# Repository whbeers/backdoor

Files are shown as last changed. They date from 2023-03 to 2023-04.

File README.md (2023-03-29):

# Backdoor Distortion Effect

This is my take on the ProCo "Rat" distortion effect, designed in [KiCAD](https://www.kicad.org/).  The design is based on widely available schematics and pretty true to the original Rat, with only a couple part value swaps that came from experimentation on a breadboard with my daughter. (She was involved in every stage of the development of this effect, and learned a ton!)

The board is built on the ["Noise Floor"](https://github.com/whbeers/noise_floor) pedal platform, which provides basic power protection, audio IO, and a footswitch with LED indicator.

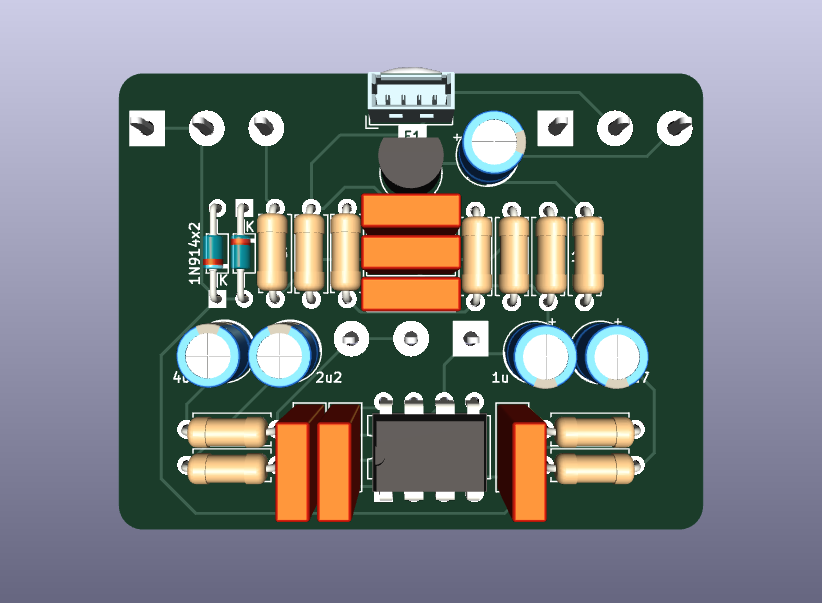
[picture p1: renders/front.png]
Front render

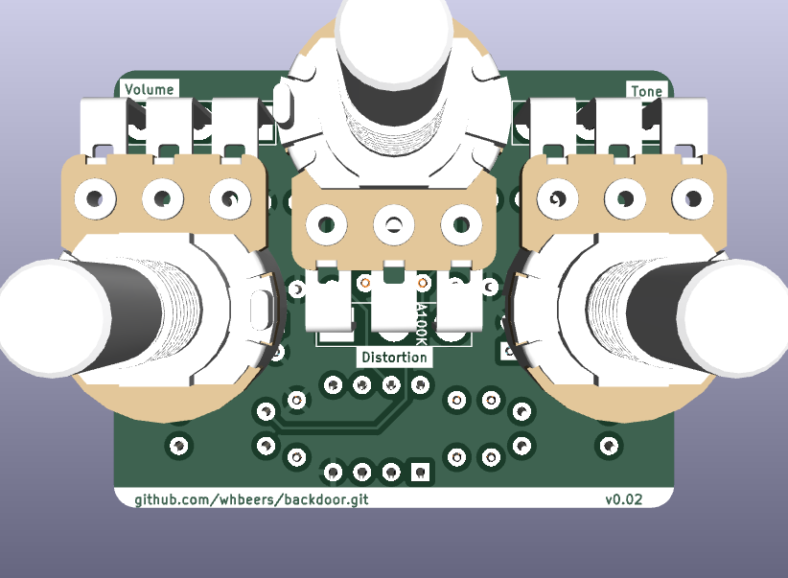
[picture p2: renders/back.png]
Back render

Schematic SVG
[Schematic PDF](schematics/backdoor-latest.pdf)

## Credit
The initial breadboarding utilized the schematic included in the ProCo Rat Analysis at [Electrosmash](https://www.electrosmash.com/proco-rat).

The Rat has a really interesting history - to learn more about it I recommend the [JHS Show episode on the subject](https://www.youtube.com/watch?v=QfwpClT_26E), and for more circuit analysis Brian Wampler has published [several](https://www.youtube.com/watch?v=zBGKdnlh4Ws) [youtube](https://www.youtube.com/watch?v=IAt-hgqrocI) [videos](https://www.youtube.com/watch?v=U2ZOTbfAcNs) going over the circuit and potential tweaks, including their own (tweaked) clone.

Thanks as always to the folks on the [freestompboxes.org](https://www.freestompboxes.org/) forum for feedback and suggestions.

Potentiometer 3D model courtesy [Vasily Kashirin](https://grabcad.com/vasily.kashirin-1).

*I am not affiliated with any of the brands, sites, or products named in this overview.*

## Versioning

My pcb designs utilize the following versioning scheme (I'll add to this as I produce more revisions):
 - v0.0XX: A candidate design that has not yet been produced and tested.
 - v0.XX: A design that has been produced, tested, and any initial errors addressed.

## Name
*The name "Backdoor" is a reflection of the nature of the effect (a RAT) and security nerdery.*

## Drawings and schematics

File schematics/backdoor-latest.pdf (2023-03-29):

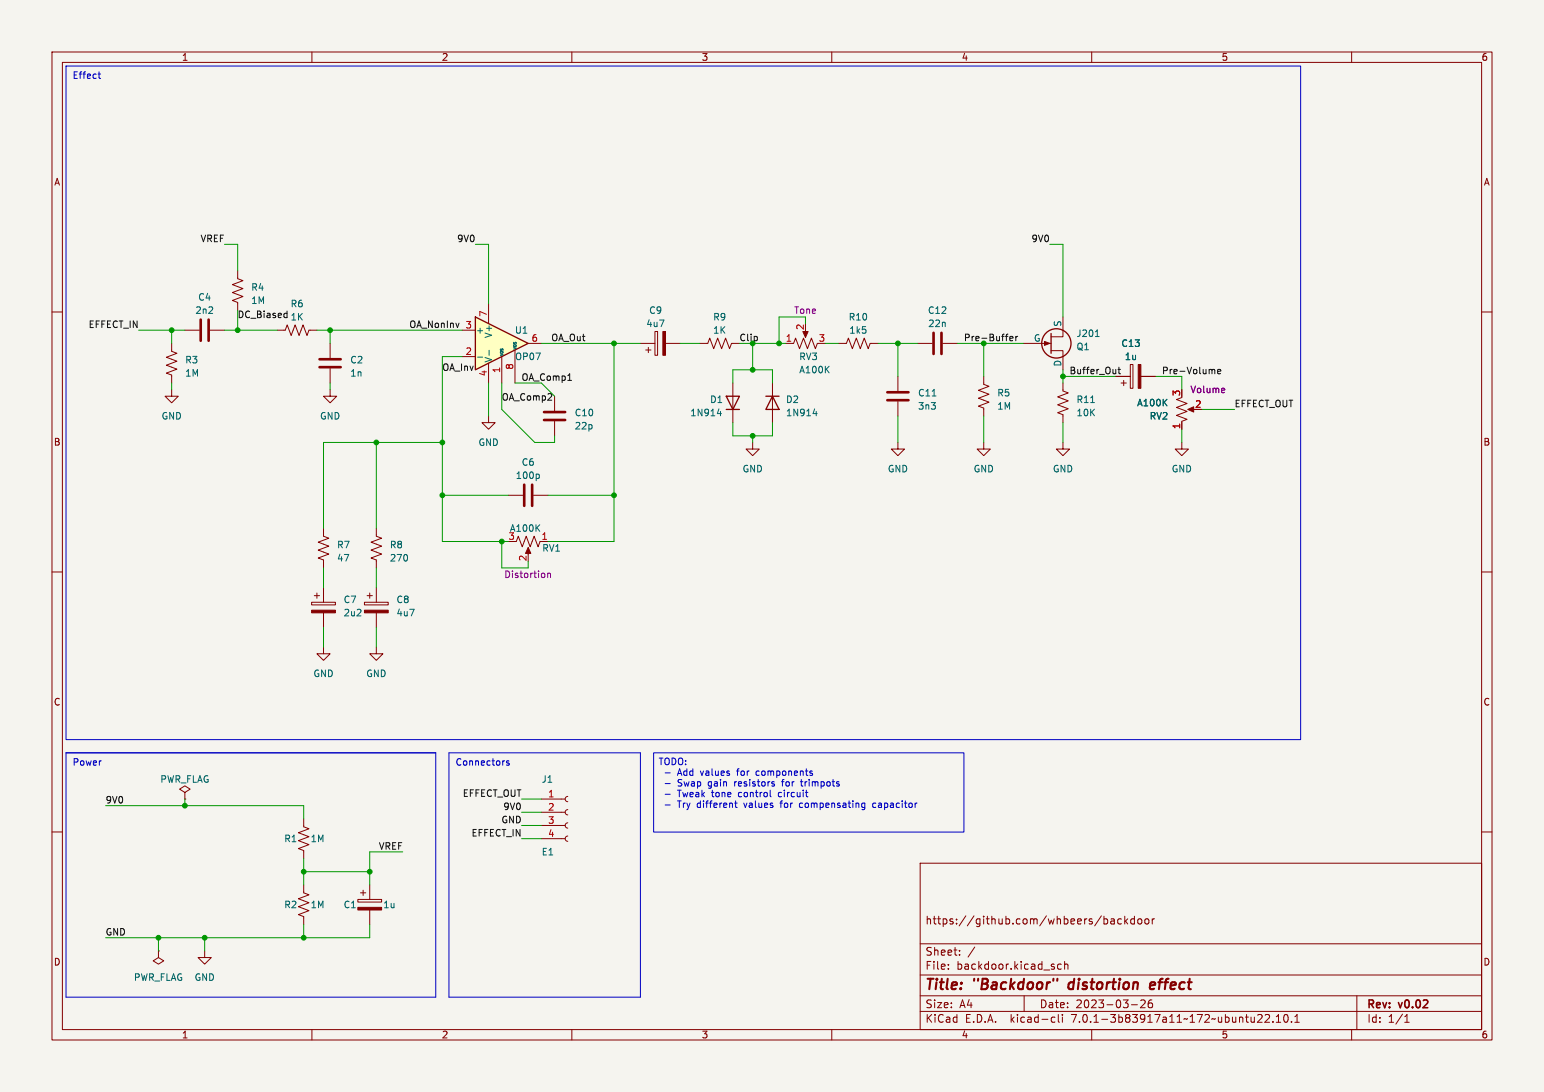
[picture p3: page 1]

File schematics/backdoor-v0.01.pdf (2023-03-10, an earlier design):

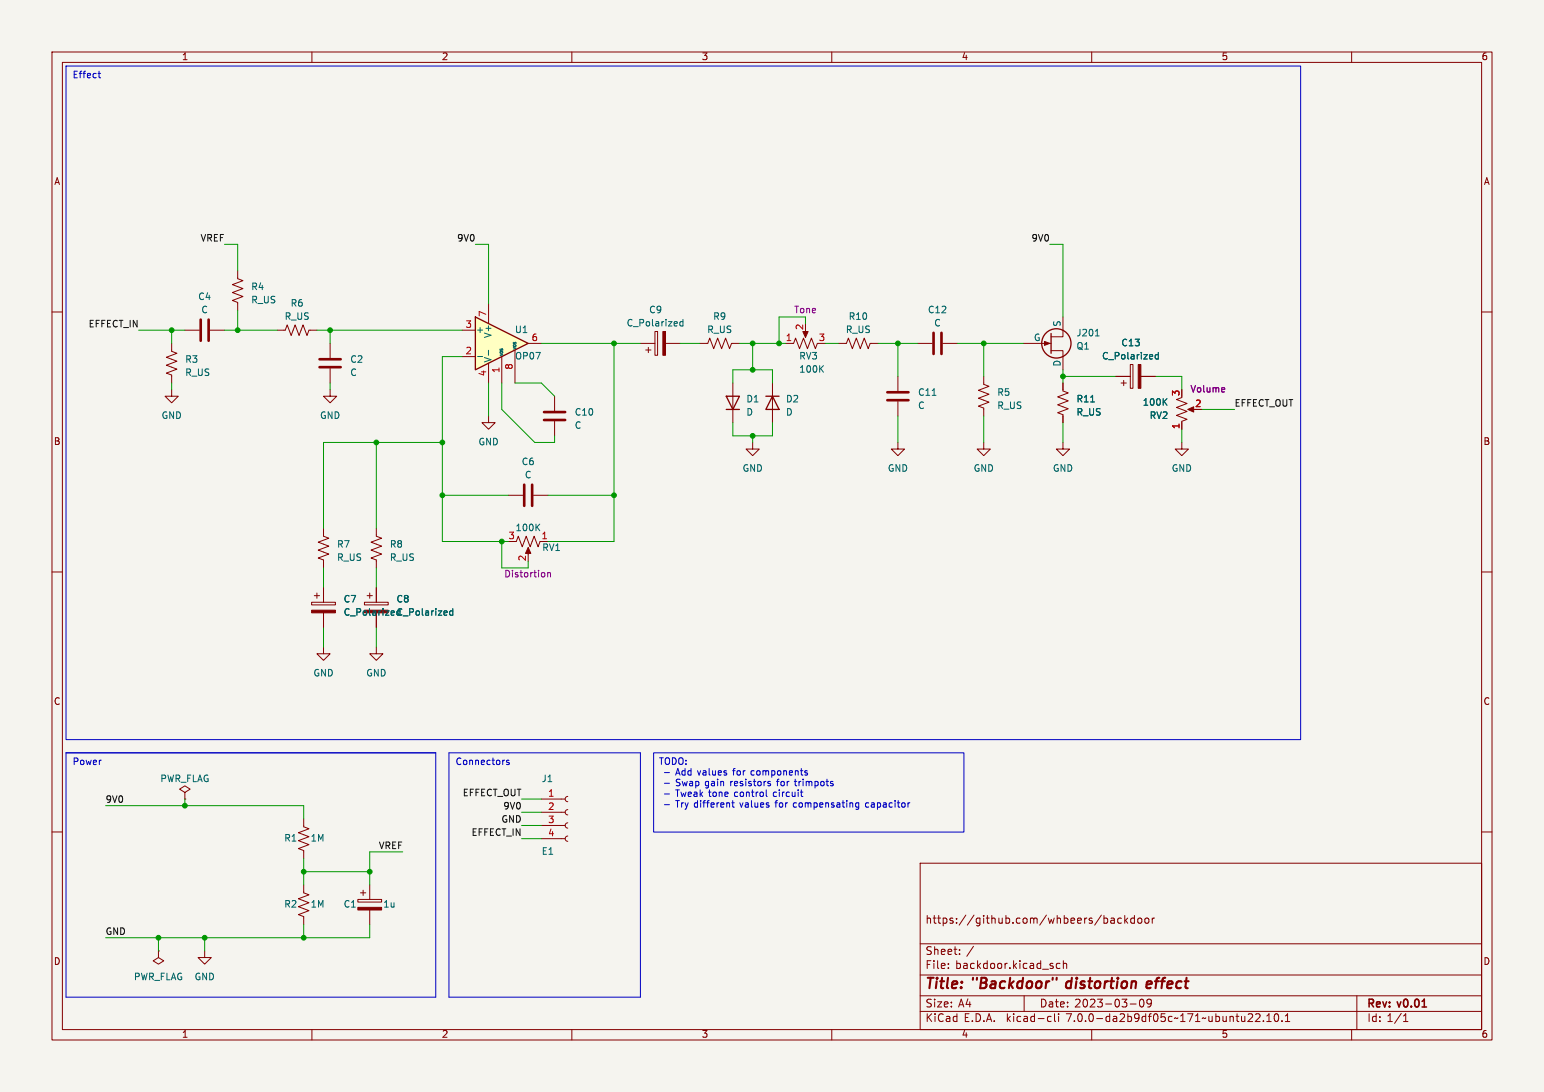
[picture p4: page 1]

- Swap gain resistors for trimpots

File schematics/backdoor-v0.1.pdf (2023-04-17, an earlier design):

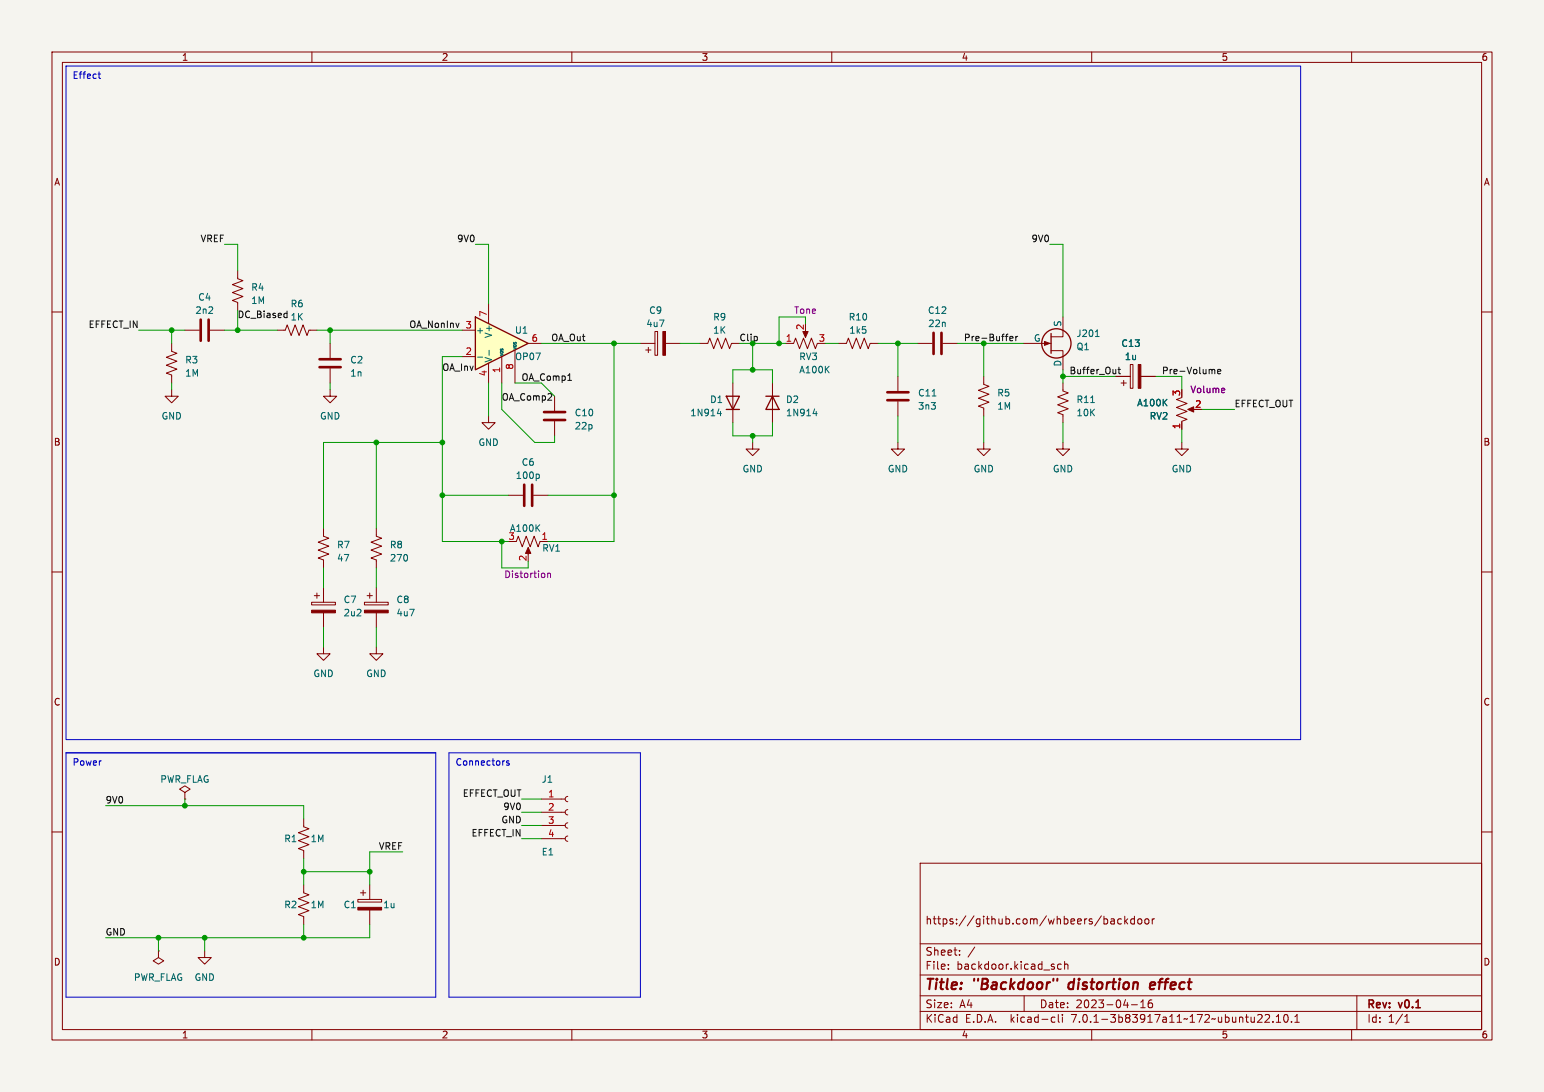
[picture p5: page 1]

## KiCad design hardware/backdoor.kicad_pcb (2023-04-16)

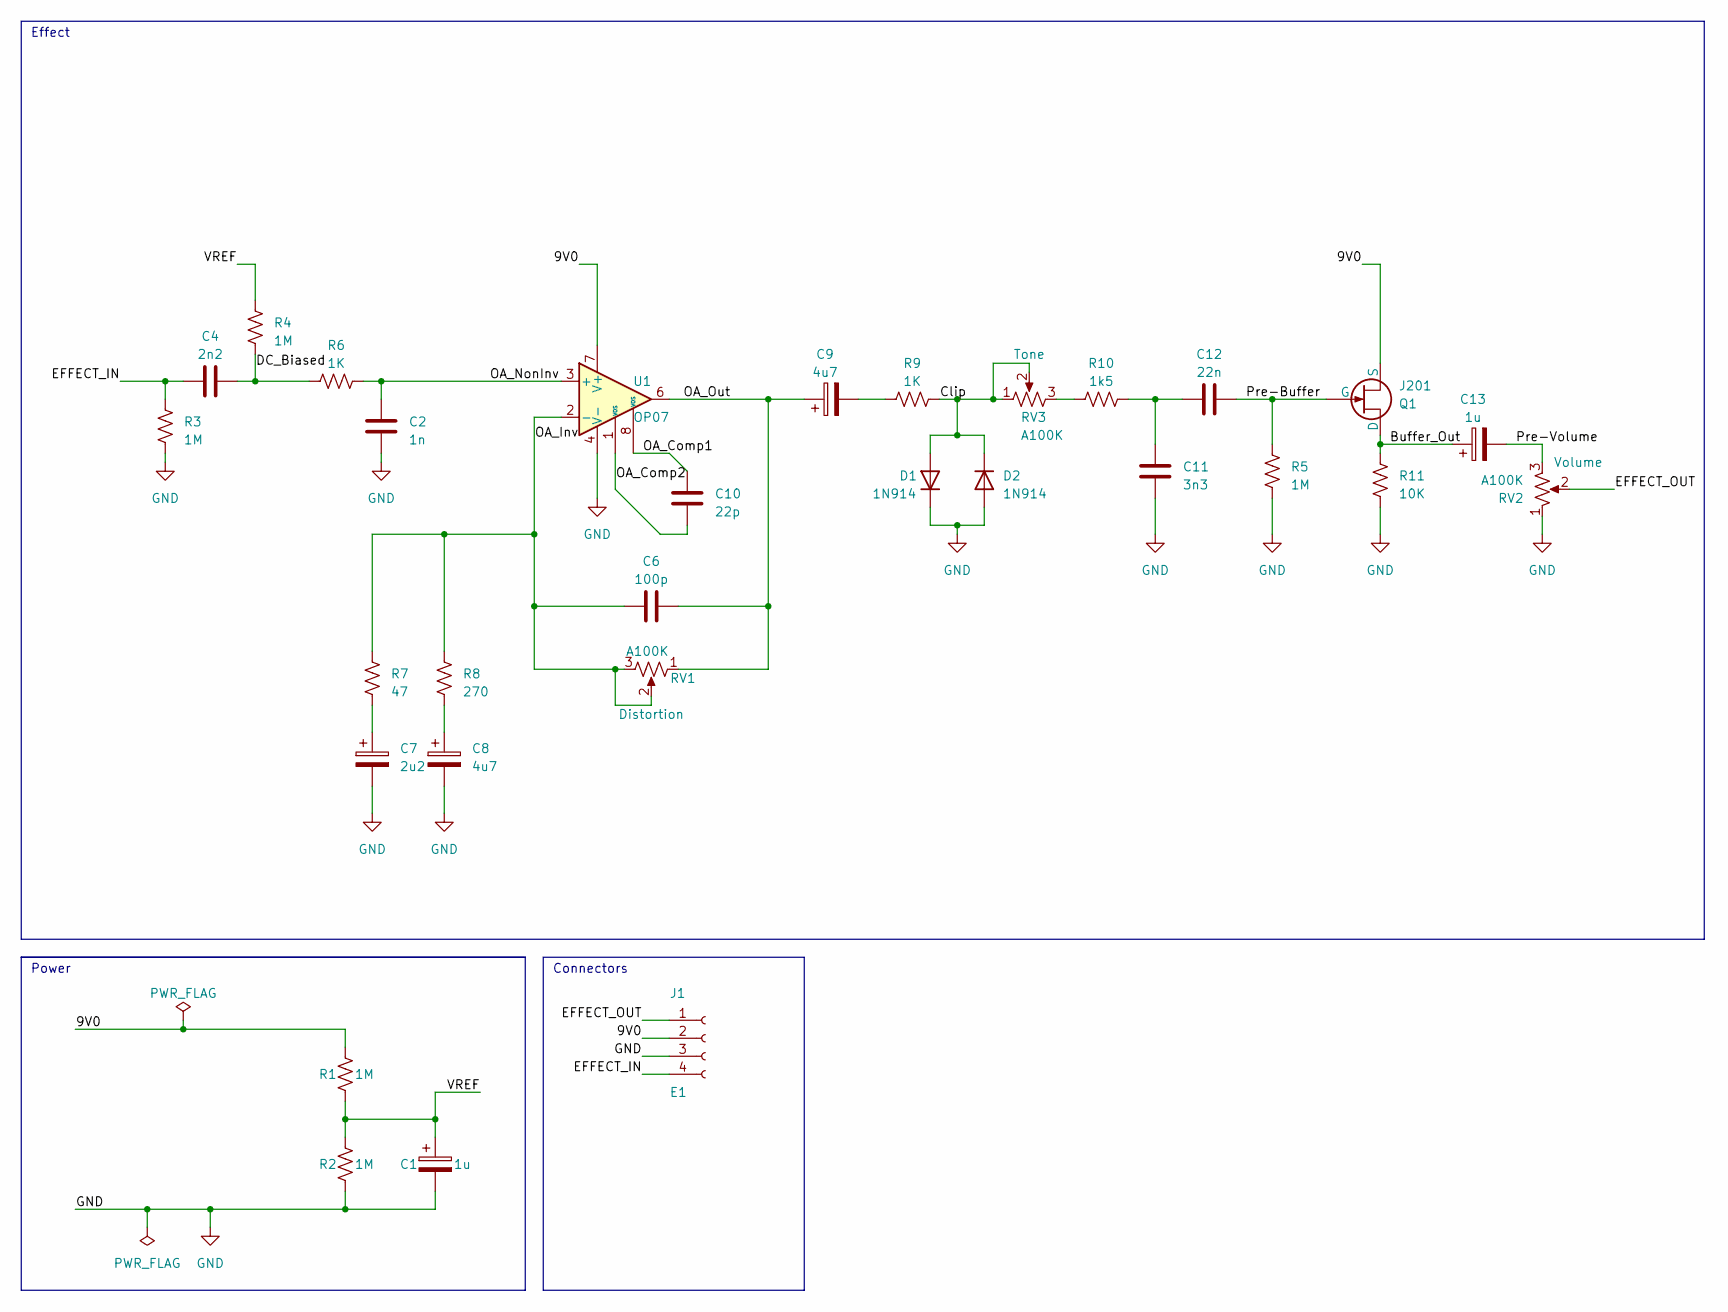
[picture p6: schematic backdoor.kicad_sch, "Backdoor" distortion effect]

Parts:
C1, C13: 1u; CP_Radial_D5.0mm_P2.50mm
C2: 1n; C_Rect_L7.2mm_W2.5mm_P5.00mm_FKS2_FKP2_MKS2_MKP2
C4: 2n2; C_Rect_L7.2mm_W2.5mm_P5.00mm_FKS2_FKP2_MKS2_MKP2
C6: 100p; C_Rect_L7.2mm_W2.5mm_P5.00mm_FKS2_FKP2_MKS2_MKP2
C7: 2u2; CP_Radial_D5.0mm_P2.50mm
C8, C9: 4u7; CP_Radial_D5.0mm_P2.50mm
C10: 22p; C_Rect_L7.2mm_W2.5mm_P5.00mm_FKS2_FKP2_MKS2_MKP2
C11: 3n3; C_Rect_L7.2mm_W2.5mm_P5.00mm_FKS2_FKP2_MKS2_MKP2
C12: 22n; C_Rect_L7.2mm_W2.5mm_P5.00mm_FKS2_FKP2_MKS2_MKP2
D1, D2: 1N914; D_DO-34_SOD68_P7.62mm_Horizontal
J1: E1; Molex_PicoBlade_53047-0410_1x04_P1.25mm_Vertical_with_3D_Mo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
Q1: J201; TO-92_Inline
R1, R2, R3, R4, R5: 1M; R_Axial_DIN0207_L6.3mm_D2.5mm_P7.62mm_Horizontal
R6, R9: 1K; R_Axial_DIN0207_L6.3mm_D2.5mm_P7.62mm_Horizontal
R7: 47; R_Axial_DIN0207_L6.3mm_D2.5mm_P7.62mm_Horizontal
R8: 270; R_Axial_DIN0207_L6.3mm_D2.5mm_P7.62mm_Horizontal
R10: 1k5; R_Axial_DIN0207_L6.3mm_D2.5mm_P7.62mm_Horizontal
R11: 10K; R_Axial_DIN0207_L6.3mm_D2.5mm_P7.62mm_Horizontal
RV1, RV2, RV3: A100K; Potentiometer_Single_3_Horizontal
U1: OP07; DIP-8_W7.62mm

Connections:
/9V0: J1.2, Q1.1 (S), R1.2, U1.7 (V+)
/Buffer_Out: C13.1, Q1.2 (D), R11.1
/Clip: D1.2 (A), D2.1 (K), R9.2, RV3.1, RV3.2
/DC_Biased: C4.2, R4.2, R6.1
/EFFECT_IN: C4.1, J1.4, R3.1
/EFFECT_OUT: J1.1, RV2.2
/OA_Comp1: C10.2, U1.8 (VOS)
/OA_Comp2: C10.1, U1.1 (VOS)
/OA_Inv: C6.1, R7.1, R8.1, RV1.2, RV1.3, U1.2 (-)
/OA_NonInv: C2.1, R6.2, U1.3 (+)
/OA_Out: C6.2, C9.1, RV1.1, U1.6
/Pre-Buffer: C12.2, Q1.3 (G), R5.1
/Pre-Volume: C13.2, RV2.3
/VREF: C1.1, R1.1, R2.2, R4.1
GND: C1.2, C2.2, C7.2, C8.2, C11.2, D1.1 (K), D2.2 (A), J1.3, R2.1, R3.2, R5.2, R11.2, RV2.1, U1.4 (V-)
unnamed: C7.1, R7.2
unnamed: C8.1, R8.2
unnamed: C9.2, R9.1
unnamed: C11.1, C12.1, R10.2
unnamed: R10.1, RV3.3

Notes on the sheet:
Connectors
Power
Effect

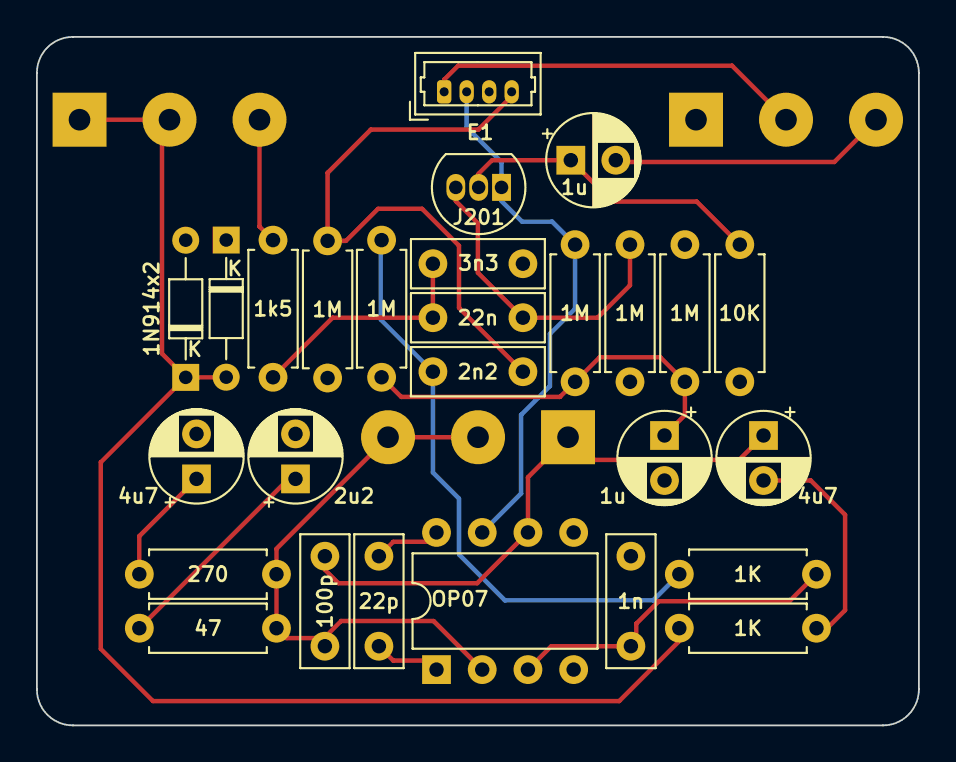
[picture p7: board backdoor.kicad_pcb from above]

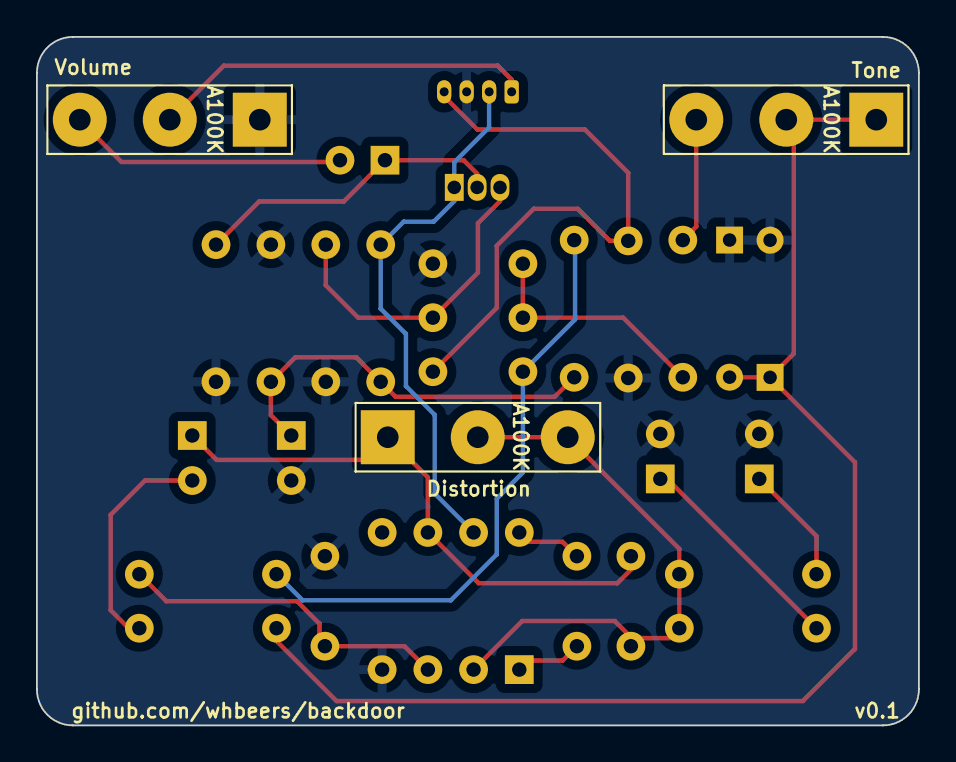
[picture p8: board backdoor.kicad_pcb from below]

Board: 2 copper layers, 49.0 x 38.2 mm, 30 parts (3 on the bottom side), 20 nets.

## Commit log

2023-03-10 initial (empty) project for backdoor RAT effect
    [backdoor.kicad_pcb, backdoor.kicad_sch]
2023-03-10 initial schematic for Backdoor
    [backdoor.kicad_pcb, backdoor.kicad_sch]
2023-03-19 Add values after experimenting on the breadboard
    [backdoor.kicad_pcb, backdoor.kicad_sch]
2023-03-26 initial layout and renders, bump rev to v0.02
    [backdoor.kicad_pcb, backdoor.kicad_sch]
2023-03-29 Routed v0.02, ready for fabrication
    [backdoor.kicad_pcb]
2023-04-16 Fix issue identified in v0.02 hardware
    - update schematic to use correct pin for jfet output buffer
    [backdoor.kicad_pcb, backdoor.kicad_sch]
2023-04-17 update schematic
